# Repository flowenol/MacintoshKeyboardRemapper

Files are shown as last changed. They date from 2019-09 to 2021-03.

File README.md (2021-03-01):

# MacintoshKeyboardRemapper

This is an Arduino project which allows to customize Macintosh 128k/512k/Plus M0110 keyboard layout. Currently I have remapped some of the international layout keyboard keys to match their equivalents in english versions of early Macintosh System.

Custom Eagle board and schematics have been added in case you wanted to assemble the dedicated device. There is also a simple case available for 3D printing on [tinkercad](https://www.tinkercad.com/things/eFeMwL3gJX1-mackeyboardremapperbox).

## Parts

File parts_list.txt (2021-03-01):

Partlist

Exported from KeyboardRemapper.sch at 22/11/2019 23:16

EAGLE Version 7.2.0 Copyright (c) 1988-2014 CadSoft

Assembly variant: 

Part     Value          Device        Package        Library   Sheet

ATM328   ATMEGA328-20P  ATMEGA328-20P DIL28-3        atmega328 1
C1       22pF           CAPPTH2       CAP-PTH-SMALL2 SparkFun  1
C2       22pF           CAPPTH2       CAP-PTH-SMALL2 SparkFun  1
KBD      RJ9PTH         RJ9PTH        RJ9            SparkFun  1
MAC      RJ9PTH         RJ9PTH        RJ9            SparkFun  1
PWR      M01PTH         M01PTH        1X01           SparkFun  1
R1       1K             RESISTORPTH1  AXIAL-0.3      SparkFun  1
R2       1K             RESISTORPTH1  AXIAL-0.3      SparkFun  1
R3       1K             RESISTORPTH1  AXIAL-0.3      SparkFun  1
R4       1K             RESISTORPTH1  AXIAL-0.3      SparkFun  1
RS232                   M03PTH        1X03           SparkFun  1
SPI                     M05PTH        1X05           SparkFun  1
XTAL     16Mhz          XTAL/S        QS             special   1

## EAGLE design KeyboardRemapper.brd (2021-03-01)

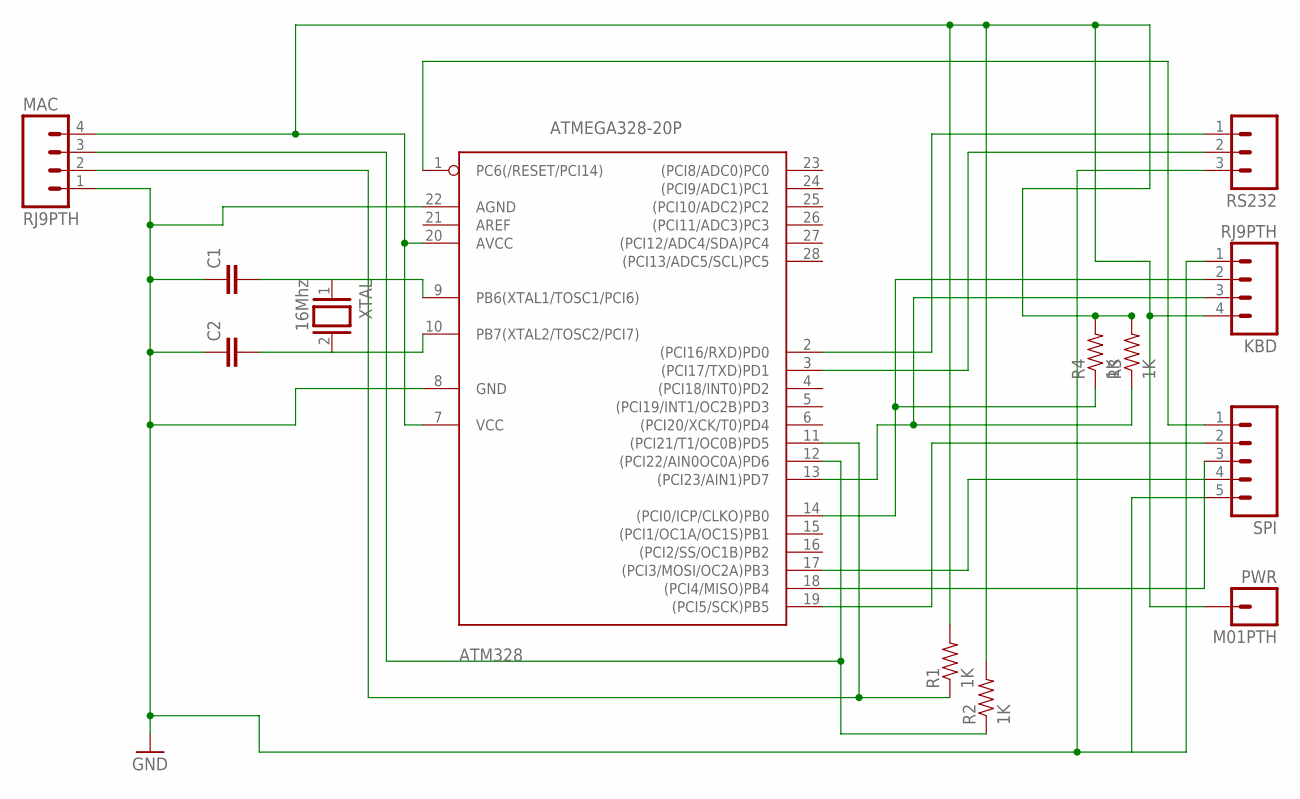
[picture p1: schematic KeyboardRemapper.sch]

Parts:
ATM328: ATMEGA328-20P; DIL28-3
C1, C2: CAPPTH2; CAP-PTH-SMALL2
KBD: RJ9PTH; RJ9
MAC: RJ9PTH; RJ9
PWR: M01PTH; 1X01
R1, R2, R3, R4: 1K; AXIAL-0.3
RS232: M03PTH; 1X03
SPI: M05PTH; 1X05
XTAL: 16Mhz; QS

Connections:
GND: ATM328.8 (GND), ATM328.22 (AGND), C1.1, C2.1, KBD.1, MAC.1, RS232.3, SPI.5
KBD_CLK: ATM328.14 ((PCI0/ICP/CLKO)PB0), KBD.2, R4.P$1 (1)
KBD_DATA: ATM328.13 ((PCI23/AIN1)PD7), KBD.3, R3.P$1 (1)
MAC_CLK: ATM328.11 ((PCI21/T1/OC0B)PD5), MAC.2, R1.P$1 (1)
MAC_DATA: ATM328.12 ((PCI22/AIN0OC0A)PD6), MAC.3, R2.P$1 (1)
MISO: ATM328.18 ((PCI4/MISO)PB4), SPI.3
MOSI: ATM328.17 ((PCI3/MOSI/OC2A)PB3), SPI.4
unnamed: ATM328.10 (PB7(XTAL2/TOSC2/PCI7)), C2.2, XTAL.2
unnamed: ATM328.9 (PB6(XTAL1/TOSC1/PCI6)), C1.2, XTAL.1
unnamed: ATM328.2 ((PCI16/RXD)PD0), RS232.1
unnamed: ATM328.3 ((PCI17/TXD)PD1), RS232.2
PWR: ATM328.7 (VCC), ATM328.20 (AVCC), KBD.4, MAC.4, PWR.1, R1.P$2 (2), R2.P$2 (2), R3.P$2 (2), R4.P$2 (2)
RST: ATM328.1 (PC6(/RESET/PCI14)), SPI.1
SCK: ATM328.19 ((PCI5/SCK)PB5), SPI.2

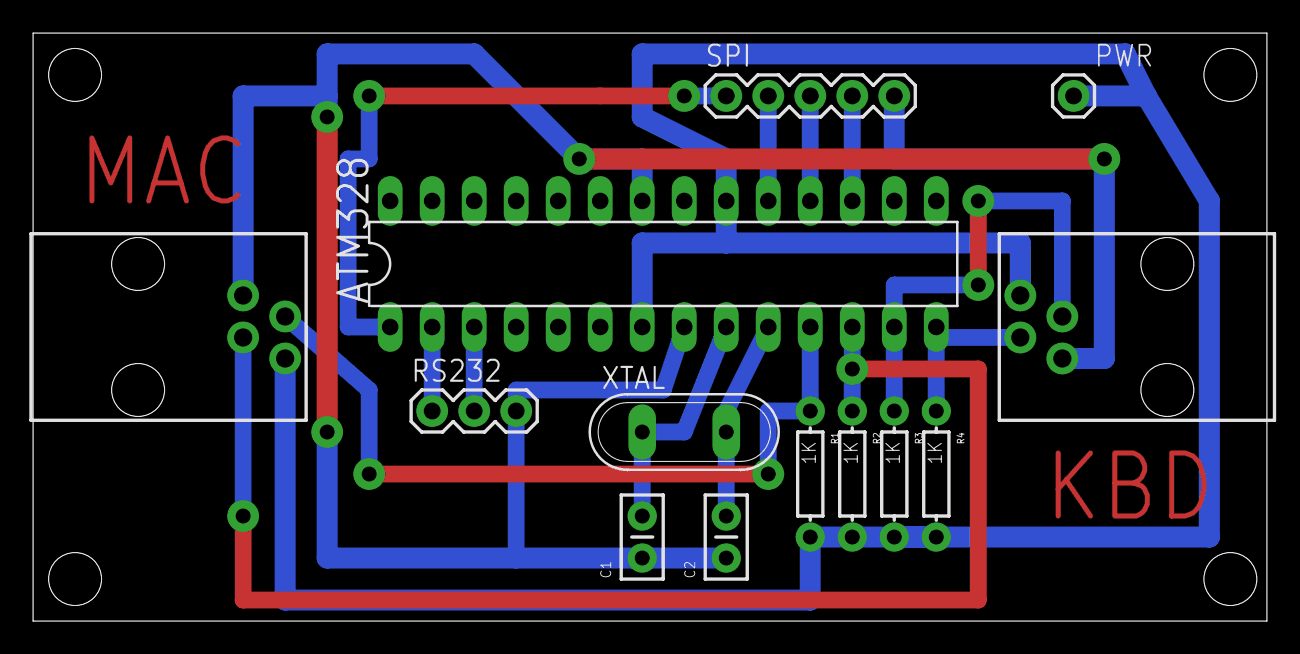
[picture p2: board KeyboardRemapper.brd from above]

Board: 2 copper layers, 74.6 x 35.5 mm, 13 parts (0 on the bottom side), 14 nets.

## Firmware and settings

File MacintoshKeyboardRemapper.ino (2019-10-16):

#define CLK_MAC 5
#define DATA_MAC 6

#define CLK_KBD 8
#define DATA_KBD 7

#define CLOCK_START_MSEC 500
#define CLOCK_TRANSITION_USEC 300
#define CLOCK_READ_LOW_USEC 180
#define CLOCK_READ_HIGH_USEC 200
#define CLOCK_WRITE_LOW_USEC 180
#define CLOCK_WRITE_HIGH_USEC 200
#define MAC_RESP_DELAY_MSEC 240
#define MAC_DETECT_READY_USEC 300

#define KBD_BUFFER_SIZE 4

// command constants
const byte MODEL_NUMBER_CMD = 0x16;
const byte TEST_CMD = 0x36;
const byte INQUIRY_CMD = 0x10;
const byte INSTANT_CMD = 0x14;

// command response constants
const byte NULL_TRANSITION = 0x7B;
const byte TEST_ACK = 0x7D;
const byte TEST_NAK = 0x77;
const byte BAD_CMD = 0x00;

enum kbd_state { 
  REQUIRE_MODEL_NUMBER,
  READ_MODEL_NUMBER,
  REQUIRE_TEST,
  READ_TEST,
  REQUIRE_INQUIRY,
  READ_INQUIRY,
  DELAY_INQUIRY
};

enum mac_state {
  DETECT_READY_FOR_CMD,
  READ_CMD,
  DETECT_READY_FOR_DATA,
  WRITE_DATA
};

// keyboard state variables
kbd_state keyboard_state = REQUIRE_MODEL_NUMBER;
boolean kbd_clock_detected;
boolean kbd_clock_state;
boolean kbd_clock_read;
unsigned int kbd_clock_count;
unsigned long kbd_clock_start;
unsigned long kbd_clock_transition_start;
unsigned long kbd_delay_start;

byte kbd_data_read;
byte kbd_last_data_read[KBD_BUFFER_SIZE];
short kbd_last_data_read_index = -1;
byte model_number;

// macintosh state variables
mac_state macintosh_state = DETECT_READY_FOR_CMD;
boolean mac_ready_detected;
unsigned long mac_delay_start;
boolean mac_clock_started;
boolean mac_clock_state;
unsigned int mac_clock_count;
unsigned long mac_clock_delay_start;
unsigned long mac_cmd_response_delay_start;

byte mac_data_read;
byte last_mac_cmd;
byte mac_data_write;


void setup() {
  pinMode(CLK_MAC, OUTPUT);
  digitalWrite(CLK_MAC, HIGH);
  pinMode(CLK_KBD, INPUT);
  kbd_hard_reset();
  //Serial.begin(19200);
}

void loop() {
  switch (keyboard_state) {
    case REQUIRE_MODEL_NUMBER:
      send_data_to_kbd(MODEL_NUMBER_CMD, READ_MODEL_NUMBER);
      break;
    case READ_MODEL_NUMBER:
      read_data_from_kbd(REQUIRE_TEST);
      break;
    case REQUIRE_TEST:
      send_data_to_kbd(TEST_CMD, READ_TEST);
      break;
    case READ_TEST:
      read_data_from_kbd(REQUIRE_INQUIRY);
      break;
    case REQUIRE_INQUIRY:
      send_data_to_kbd(INQUIRY_CMD, READ_INQUIRY);
      break;
    case READ_INQUIRY:
      read_data_from_kbd(REQUIRE_INQUIRY);
      break;
  }

  switch (macintosh_state) {
    case DETECT_READY_FOR_CMD:
      mac_detect_ready_to_send_cmd();
      break;
    case READ_CMD:
      mac_read_data();
      break;
    case DETECT_READY_FOR_DATA:
      mac_detect_ready_to_recv_data();
      break;
    case WRITE_DATA:
      mac_write_data();
      break;
  }
  
}

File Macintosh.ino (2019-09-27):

void mac_detect_ready_to_send_cmd() {
  if (!mac_ready_detected) {
    pinMode(DATA_MAC, INPUT);
    if (digitalRead(DATA_MAC) == LOW) {
      mac_ready_detected = true;  
    }
  } else {
    if (mac_delay_start == 0) {
      mac_delay_start = micros(); 
    }

    if (micros() - mac_delay_start >= MAC_DETECT_READY_USEC) {
      mac_reset();
      macintosh_state = READ_CMD;
    }
  }
}

void mac_detect_ready_to_recv_data() {
  if (mac_delay_start == 0) {
    mac_delay_start = micros(); 
    pinMode(DATA_MAC, INPUT);
  }

  if (micros() - mac_delay_start >= 400) {
    if (digitalRead(DATA_MAC) == HIGH) {
      macintosh_state = WRITE_DATA;
    } else {
      macintosh_state = DETECT_READY_FOR_CMD;
    }
    mac_reset();
  }
}

void mac_read_data() {
  if (!mac_clock_started) {
    pinMode(DATA_MAC, INPUT);
    mac_clock_state = LOW;
    mac_clock_started = true;
  }

  if (mac_clock_state == LOW) {
    if (mac_clock_delay_start == 0) {
      digitalWrite(CLK_MAC, LOW);
      mac_clock_delay_start = micros();
    }

    if (micros() - mac_clock_delay_start >= CLOCK_READ_LOW_USEC) {
      mac_clock_state = HIGH;
      mac_clock_delay_start = 0;  
    }
  }

  if (mac_clock_state == HIGH) {
    if (mac_clock_delay_start == 0) {
      digitalWrite(CLK_MAC, HIGH);
      mac_clock_delay_start = micros();
      
      if (digitalRead(DATA_MAC) == HIGH) {
        mac_data_read |= 1<<(7 - mac_clock_count);  
      }
    }

    if (micros() - mac_clock_delay_start >= CLOCK_READ_HIGH_USEC) {
      if (mac_clock_count < 7) {
        mac_clock_state = LOW;
        mac_clock_delay_start = 0;
        mac_clock_count++;
      } else {
        last_mac_cmd = mac_data_read;
        mac_reset();
        macintosh_state = DETECT_READY_FOR_DATA;  
      }
    }
  }
}

void mac_write_data() {
  if (!mac_clock_started) {
    if (last_mac_cmd == INQUIRY_CMD && kbd_last_data_read_index == -1) {
      if (mac_cmd_response_delay_start == 0) {
        mac_cmd_response_delay_start = millis();
      }

      if (millis() - mac_cmd_response_delay_start >= MAC_RESP_DELAY_MSEC) {
        goto WRITE_MAC;
      } else {
        return;
      }
    } else {
      WRITE_MAC:
      
      mac_data_write = mac_cmd_response_data();
      if (mac_data_write == BAD_CMD) {
         mac_reset();
         macintosh_state = DETECT_READY_FOR_CMD;
         return;
      } else {
        pinMode(DATA_MAC, OUTPUT);
        mac_clock_state = LOW;
        mac_clock_started = true;
      }
    }
  }
  
  if (mac_clock_state == LOW) {
    if (mac_clock_delay_start == 0) {
      digitalWrite(CLK_MAC, LOW);
      mac_clock_delay_start = micros();

      digitalWrite(DATA_MAC, mac_data_write>>(7 - mac_clock_count) & 1 > 0);
    }

    if (micros() - mac_clock_delay_start >= CLOCK_WRITE_LOW_USEC) {
      mac_clock_state = HIGH;
      mac_clock_delay_start = 0;  
    }
  }

  if (mac_clock_state == HIGH) {
    if (mac_clock_delay_start == 0) {
      digitalWrite(CLK_MAC, HIGH);
      mac_clock_delay_start = micros();
    }

    if (micros() - mac_clock_delay_start >= CLOCK_WRITE_HIGH_USEC) {
      if (mac_clock_count < 7) {
        mac_clock_state = LOW;
        mac_clock_delay_start = 0;
        mac_clock_count++;
      } else {
        digitalWrite(DATA_MAC, HIGH);
        mac_reset();
        macintosh_state = DETECT_READY_FOR_CMD;
      }
    }
  }
}

byte mac_cmd_response_data() {
  switch (last_mac_cmd) {
    case MODEL_NUMBER_CMD:
      return model_number;
    case TEST_CMD:
      return TEST_ACK;
    case INSTANT_CMD:
    case INQUIRY_CMD:
      if (kbd_last_data_read_index == -1) {
        return NULL_TRANSITION;
      }
      byte inquiry_data = kbd_last_data_read[0];
      kbd_last_data_read[0] = kbd_last_data_read[1];
      kbd_last_data_read[1] = kbd_last_data_read[2];
      kbd_last_data_read[2] = kbd_last_data_read[3];
      kbd_last_data_read_index -= 1;
      return remap(inquiry_data);
  }
}

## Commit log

2019-10-16 keyboard pin swap
2021-03-01 Schematics, board, parts list and case project added.
    [KeyboardRemapper.brd, KeyboardRemapper.sch]
